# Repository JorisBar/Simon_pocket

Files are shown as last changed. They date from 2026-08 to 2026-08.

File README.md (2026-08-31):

# Simon_pocket – A pocket version of the classic Simon says game

<p align="center">
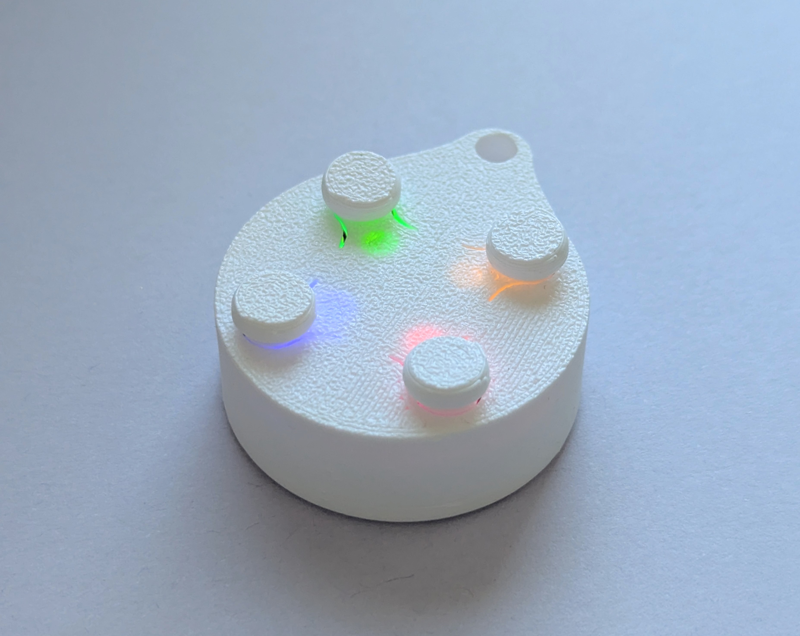
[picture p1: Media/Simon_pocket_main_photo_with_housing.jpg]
Main photo with housing
  
</p>

**Simon_pocket is a pocket sized memory training game. Players have to repeat a button sequence that gets longer each round. This project includes a custom PCB, bare metal programming for an STM32 MCU and a 3D printed housing.**

---

## Gameplay

Gameplay Diagram

---

## Hardware Architecture

Hardware Diagram

---

## Component Selection and Design Considerations

- **Microcontroller:** The STM32F030C6T6 was chosen for being inexpensive (0.5€ @ 30+ Qty) and having good documentation and support.
- **Battery:** The CR2032 was selected because of the 3V nominal voltage, compact size and availability.
- **Sound system:** Buzzers/speakers had to be omitted due to the high internal resistance of the battery.
- **Power on:** Due to space constraints, a dedicated power button was not possible. Instead, every button is configured to wake up the MCU from STOP mode.
- **Standby current:** To decrease standby current to ~6uA:
  - A low leakage current PMOS was selected.
  - No LDOs or switching regulators were used.
  - The MCU operates mostly in STOP power saving mode.

---

## PCB Design & Layout Details
<p align="center">
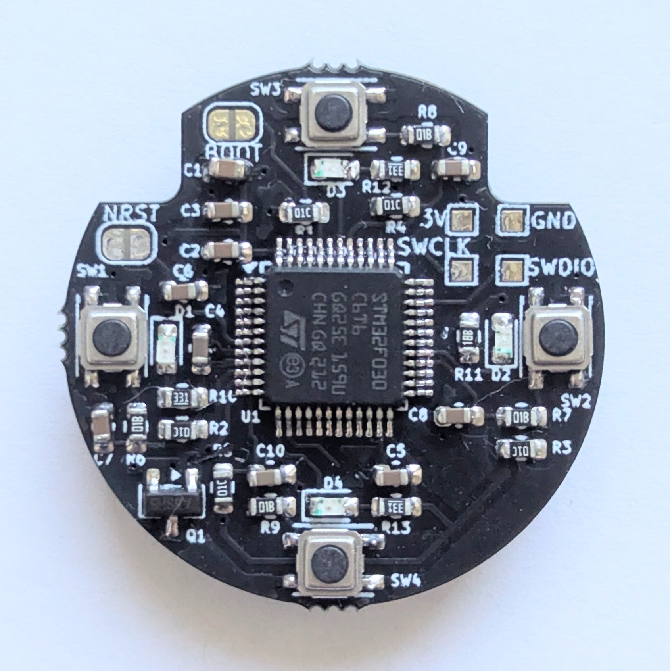
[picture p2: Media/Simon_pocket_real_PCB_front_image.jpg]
PCB top layer
  
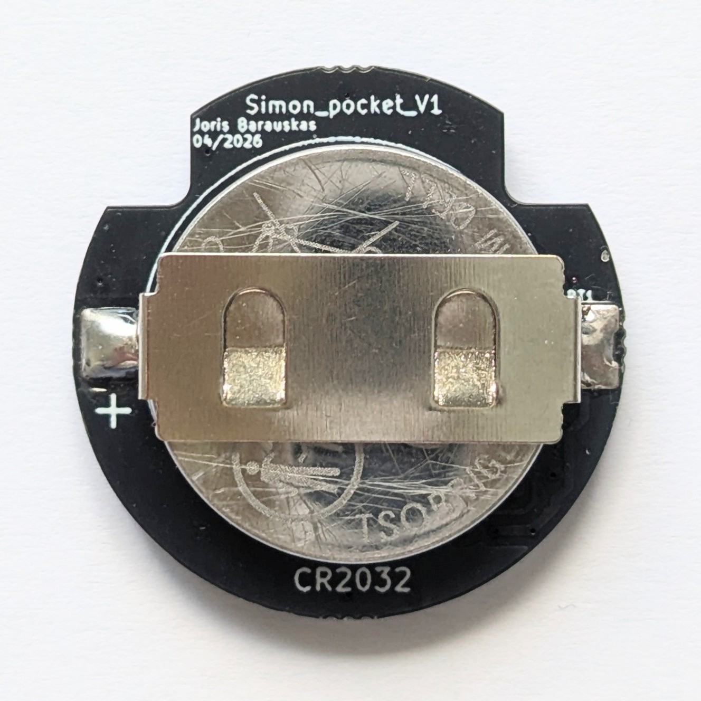
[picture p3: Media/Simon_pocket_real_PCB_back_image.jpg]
PCB bottom layer
  
</p>
<p align="center">
  PCB top layer
  PCB bottom layer
</p>

PCB Schematic
### Layer Stackup (2-Layer)
1. **Top (Signal / Power):** MCU, LED and button traces. Power distribution.
2. **Bottom (Ground / Power):** Negative battery contact and ground plane. Power distribution.

### PCB panel
A PCB panel was designed to decrease the cost of each PCB.
<p align="center">
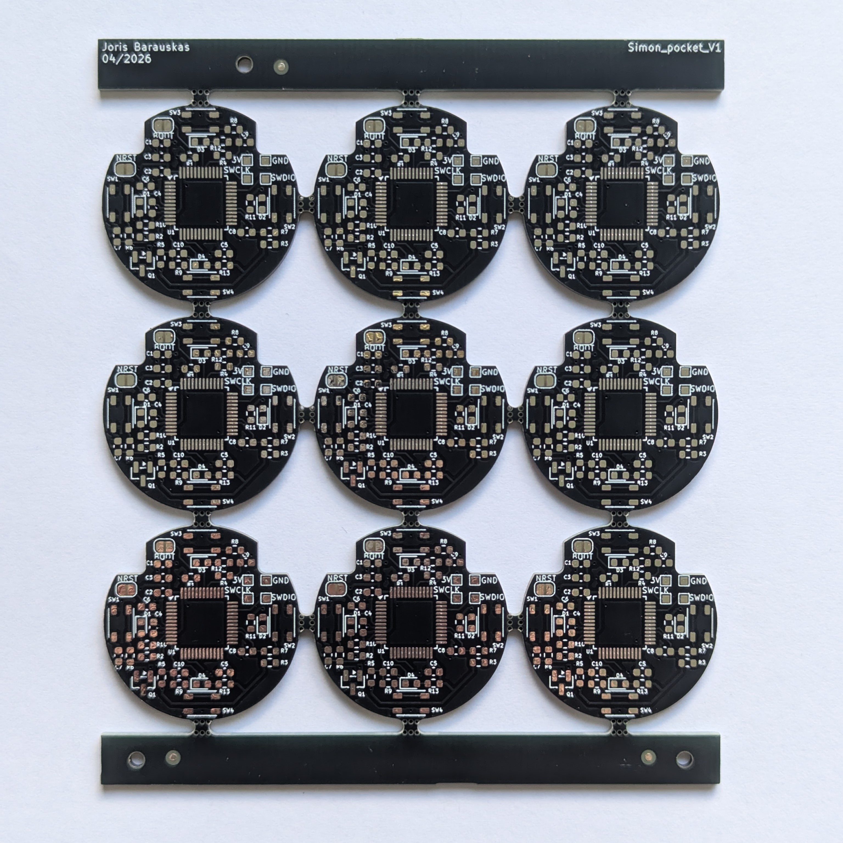
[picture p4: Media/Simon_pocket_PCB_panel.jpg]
PCB panel
  
</p>

---

## Programming
The code was written in bare metal CMSIS C using the STM32CubeIDE. To upload the code an ST-LINK V2 has to be connected to the programming contacts on the PCB.

### Code structure
Event-driven low power code structure

### State machine transitions
State machine transitions

---
## 3D modeling and printing
The housing was modeled using Autodesk Fusion. It was printed using a Bambu Lab A1 mini 3D printer.

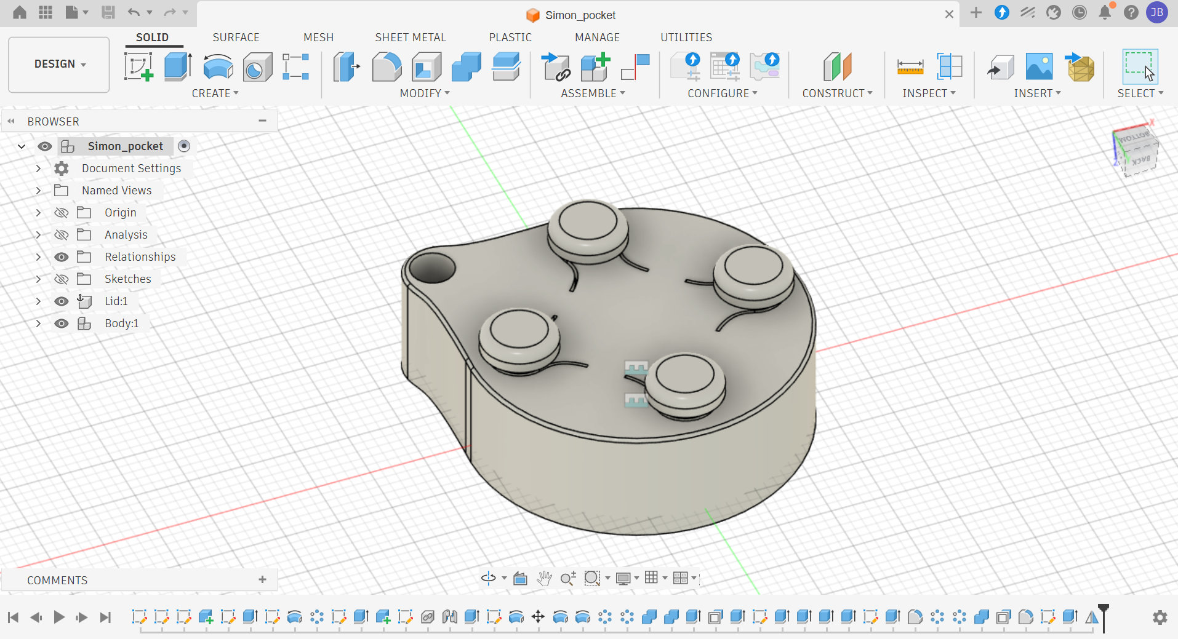
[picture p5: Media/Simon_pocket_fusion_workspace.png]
Fusion Workspace

---

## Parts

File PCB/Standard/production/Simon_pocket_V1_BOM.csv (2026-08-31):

Reference | Qty | Value | Footprint | LCSC PN
BT1 | 1 | CR2032 | My library:CR2032 slim holder | C2902340
C1 | 1 | 10u | Capacitor_SMD:C_0603_1608Metric | C6119842
C2,C3,C4,C5,C6,C7,C8,C9,C10 | 9 | 100n | Capacitor_SMD:C_0603_1608Metric | C6119867
D1 | 1 | RED | LED_SMD:LED_0603_1608Metric | C965799
D2 | 1 | GREEN | LED_SMD:LED_0603_1608Metric | C51933293
D3 | 1 | BLUE | LED_SMD:LED_0603_1608Metric | C51933294
D4 | 1 | YELLOW | LED_SMD:LED_0603_1608Metric | C51933295
Q1 | 1 | DMG2305UX-7-MS PMOS | Package_TO_SOT_SMD:SOT-23 | C7379997
R1,R2,R3,R4,R5 | 5 | 10k | Resistor_SMD:R_0603_1608Metric | C49652949
R6,R7,R8,R9 | 4 | 1k | Resistor_SMD:R_0603_1608Metric | C2907002
R10,R12,R13 | 3 | 330 | Resistor_SMD:R_0603_1608Metric | C49653542
R11 | 1 | 1.5k | Resistor_SMD:R_0603_1608Metric | C2930050
SW1,SW2,SW3,SW4 | 4 | SW_Push | My library:SW_Push mini square HansElectricity C22375378 | C22375378
U1 | 1 | STM32F030C6Tx | Package_QFP:LQFP-48_7x7mm_P0.5mm | C106925

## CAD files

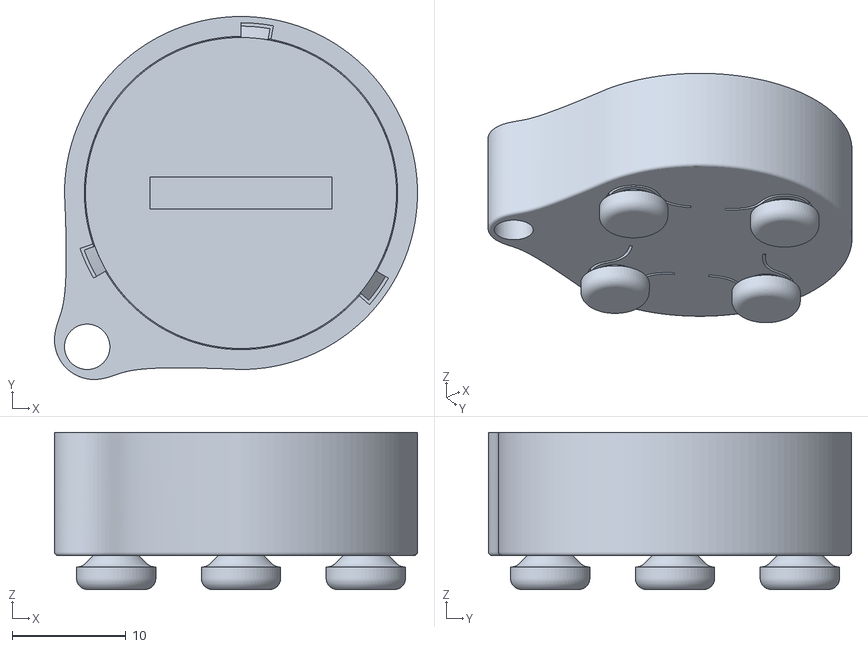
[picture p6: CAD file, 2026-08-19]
3D model/main_body_and_buttons_and_lid_V9.stl
32.0 x 32.0 x 13.8

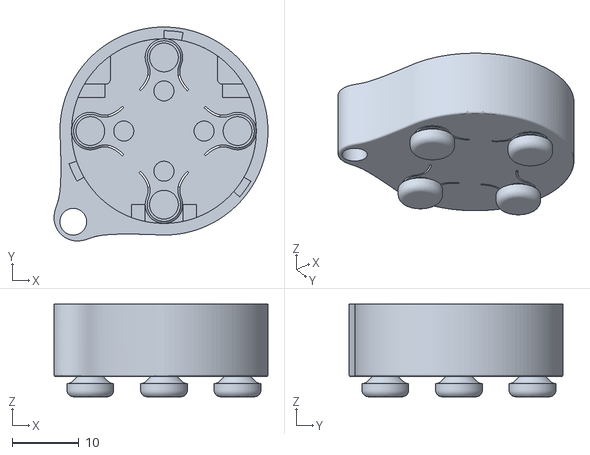
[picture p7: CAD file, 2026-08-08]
3D model/main_body_and_buttons_V8.stl
32.0 x 32.0 x 13.8

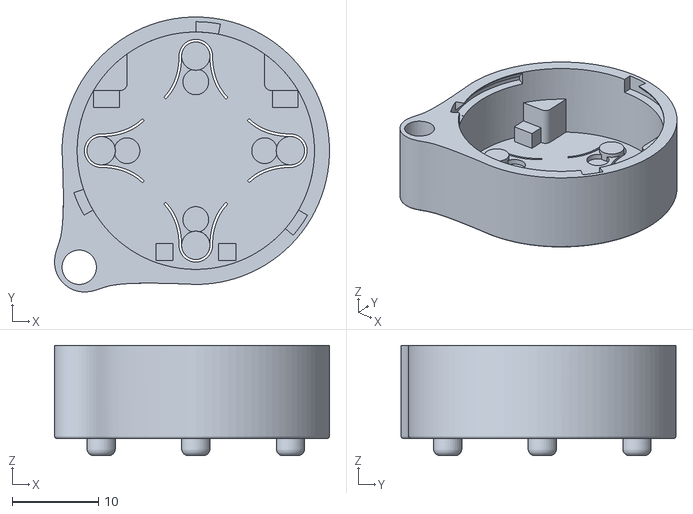
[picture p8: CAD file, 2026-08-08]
3D model/main_body_V4.stl
32.0 x 32.0 x 12.8

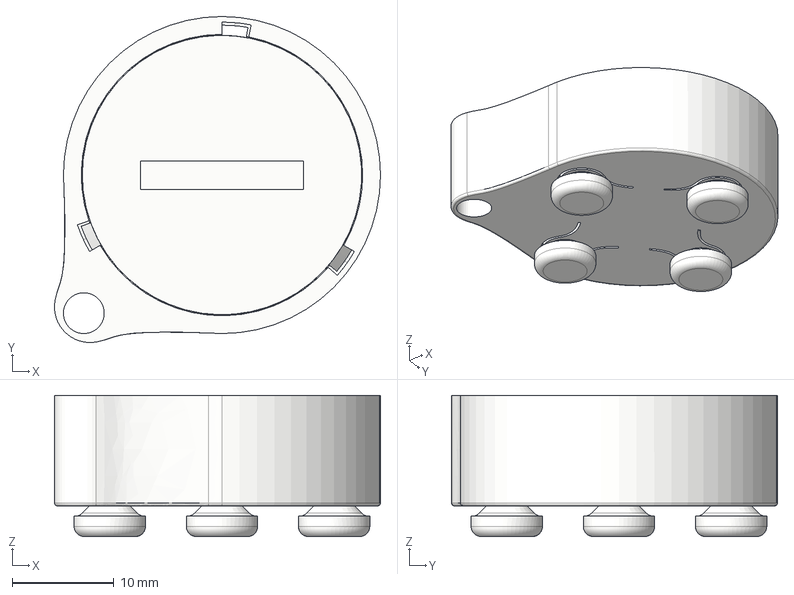
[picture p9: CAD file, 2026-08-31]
3D model/Simon_pocket_V9.step
32.0 x 32.0 x 13.8 mm

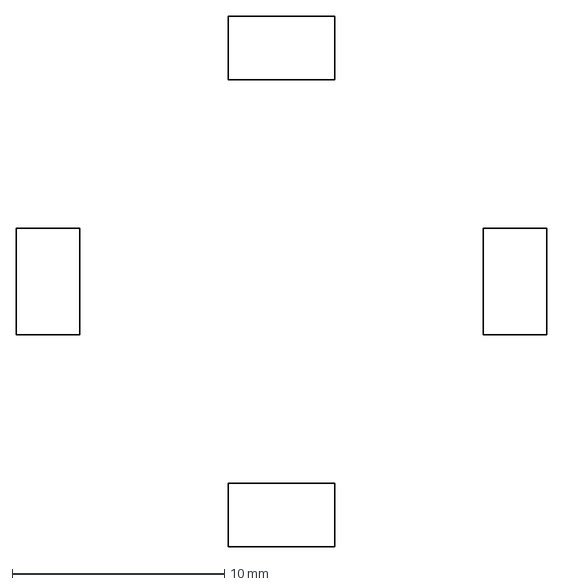
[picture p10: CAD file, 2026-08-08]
PCB/Standard/Simon says PCB buttons.dxf
25.0 x 25.0 mm

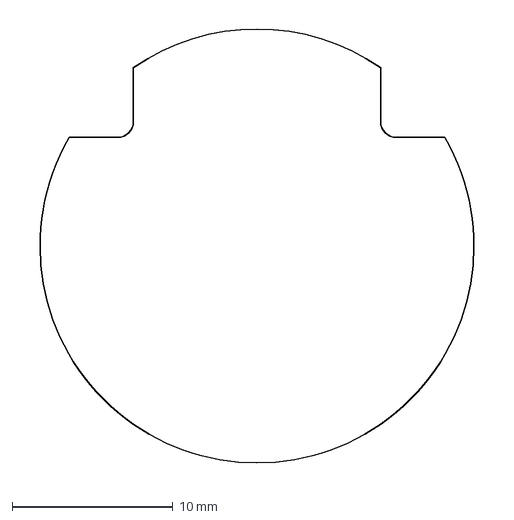
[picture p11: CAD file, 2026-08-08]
PCB/Standard/Simon says PCB.dxf
29.9 x 28.9 mm

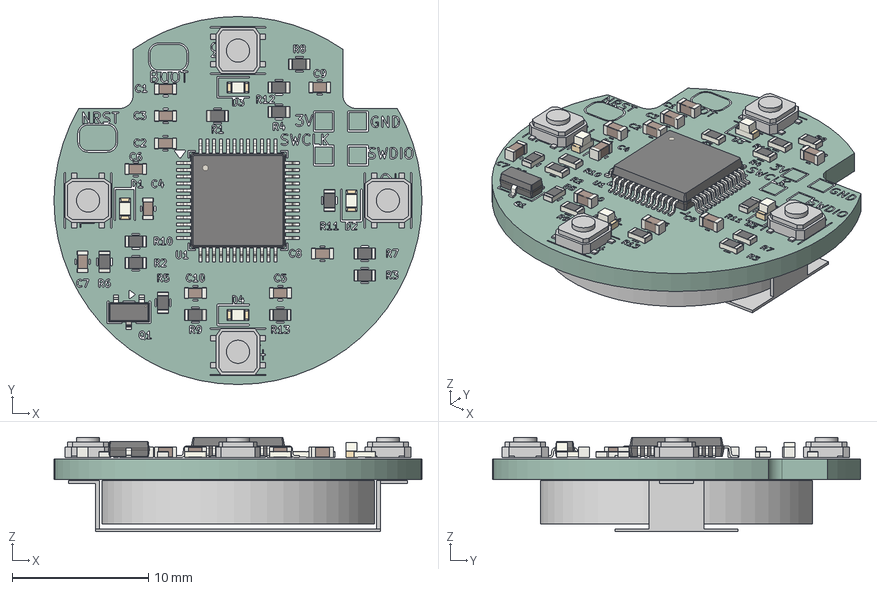
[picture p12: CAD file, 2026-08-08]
3D model/Simon_says.step
27.0 x 27.0 x 6.93 mm
KICAD small push button HansElectricity C22375378 x 4
LED_0603_1608Metric x 4
C_0603_1608Metric x 10
R_0603_1608Metric x 13
SOT-23
LQFP-48_7x7mm_P0.5mm
KICAD slim CR2032 holder
Simon_says_silkscreen x 2
Simon_says_PCB

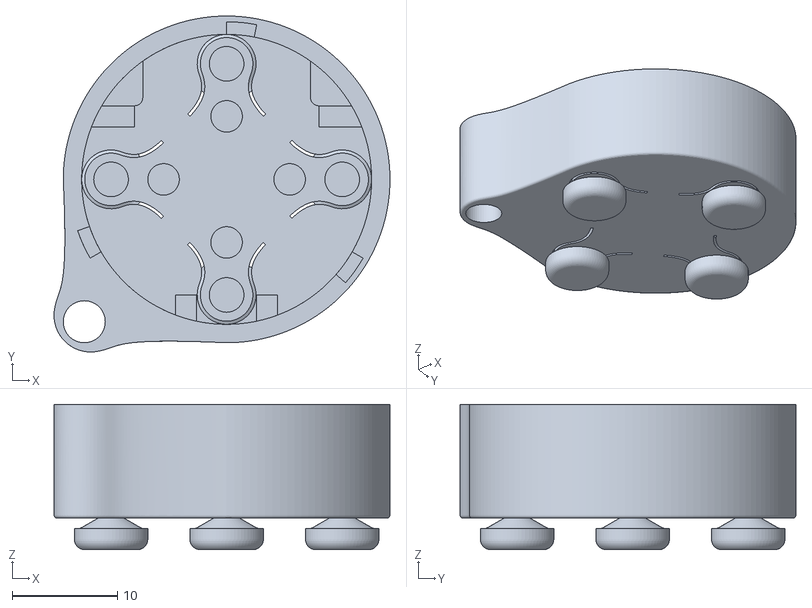
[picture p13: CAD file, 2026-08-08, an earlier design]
3D model/main_body_and_buttons_V7.stl
32.0 x 32.0 x 13.8

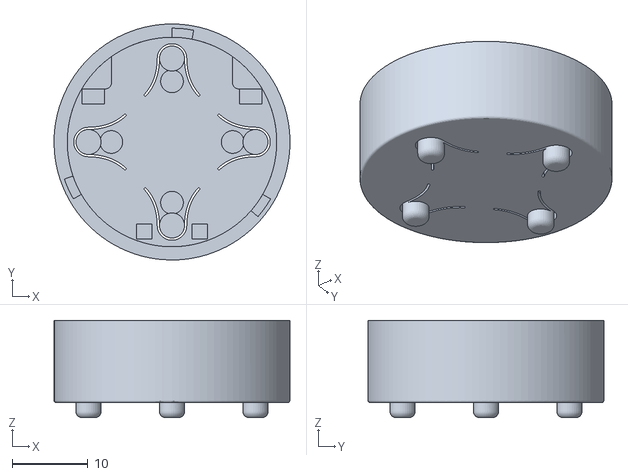
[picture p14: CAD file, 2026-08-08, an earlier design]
3D model/main_body_V3.stl
31.1 x 31.1 x 12.8

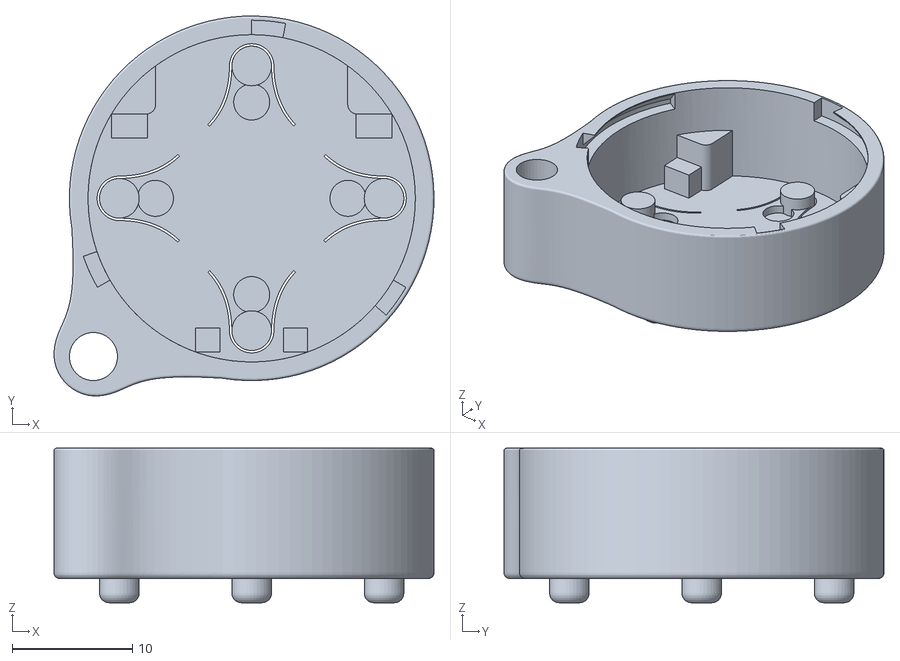
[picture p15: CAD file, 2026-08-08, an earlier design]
3D model/main_body_V1.stl
31.6 x 31.6 x 12.8

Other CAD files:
3D model/main_body_and_buttons_V5.stl
3D model/main_body_V2.stl
3D model/main_body_and_buttons_V6.stl
3D model/old_versions/Simon_pocket_V5.stl
3D model/old_versions/Simon_pocket_V2.stl
3D model/Simon_pocket_V9.f3z
3D model/old_versions/Simon_pocket_V6.stl

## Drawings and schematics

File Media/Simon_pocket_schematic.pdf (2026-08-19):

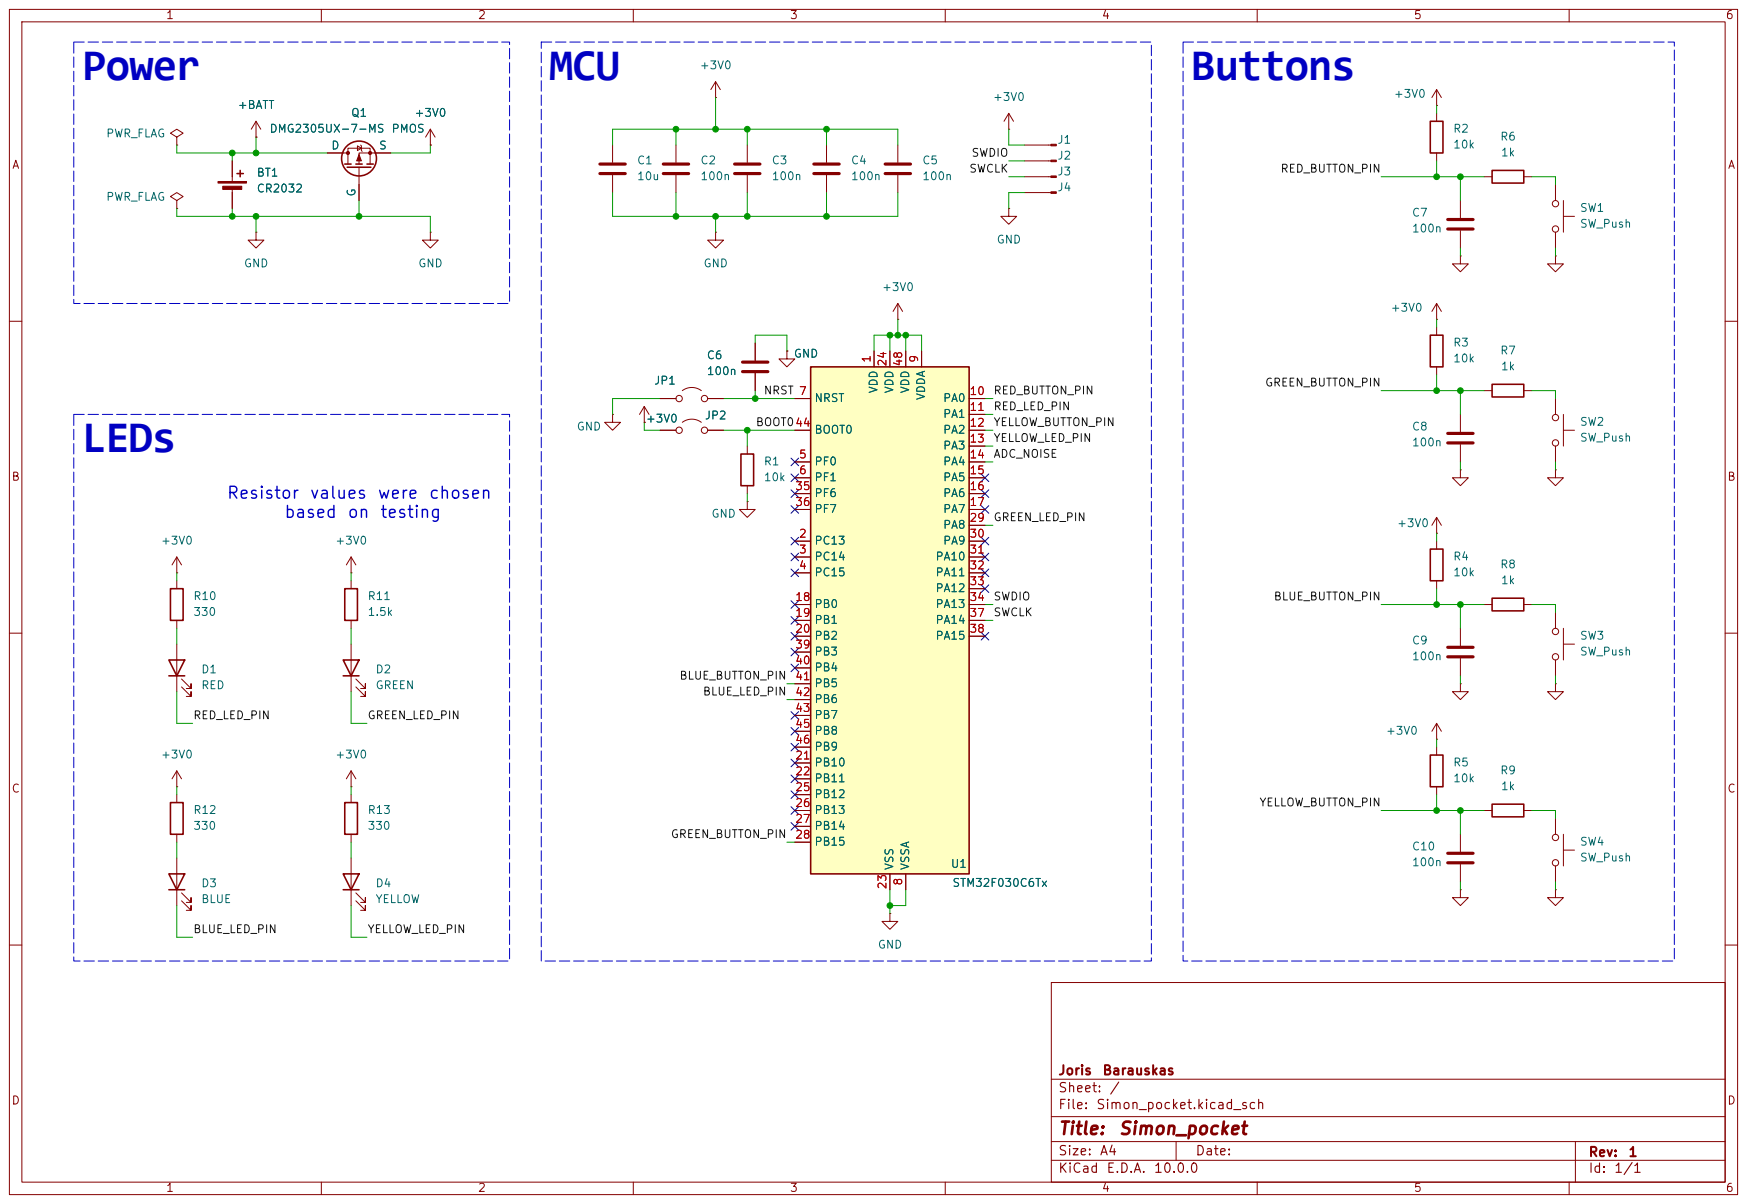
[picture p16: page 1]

1 PC13 2 PC14 3 PC15 4 PF0 5 PF1 6 NRST 7 VSSA 8 VDDA 9 PA0 10 PA1 11 PA2 12 PA3 13 PA4 14 PA5 15 PA6 16 PA7 17 PB0 18 PB1 19 PB2 20 PB10 21 PB11 22 VSS 23 VDD 24 PB12 25 PB13 26 PB14 27 PB15 28 PA8 29 PA9 30 PA10 31 PA11 32 PA12 33 PA13 34 PF6 35 PF7 36 PA14 37 PA15 38 PB3 39 PB4 40 PB5 41 PB6 42 PB7 43 BOOT0 44 PB8 45 PB9 46 VDD 48C6

1 PC13 2 PC14 3 PC15 4 PF0 5 PF1 6 NRST 7 VSSA 8 VDDA 9 PA0 10 PA1 11 PA2 12 PA3 13 PA4 14 PA5 15 PA6 16 PA7 17 PB0 18 PB1 19 PB2 20 PB10 21 PB11 22 VSS 23 VDD 24 PB12 25 PB13 26 PB14 27 PB15 28 PA8 29 PA9 30 PA10 31 PA11 32 PA12 33 PA13 34 PF6 35 PF7 36 PA14 37 PA15 38 PB3 39 PB4 40 PB5 41 PB6 42 PB7 43 BOOT0 44 PB8 45 PB9 46 VDD 48 U1
GND VDD

Resistor values were chosen

Size: A4 | Rev: 1
KiCad E.D.A. 10.0.0 | Id: 1/1

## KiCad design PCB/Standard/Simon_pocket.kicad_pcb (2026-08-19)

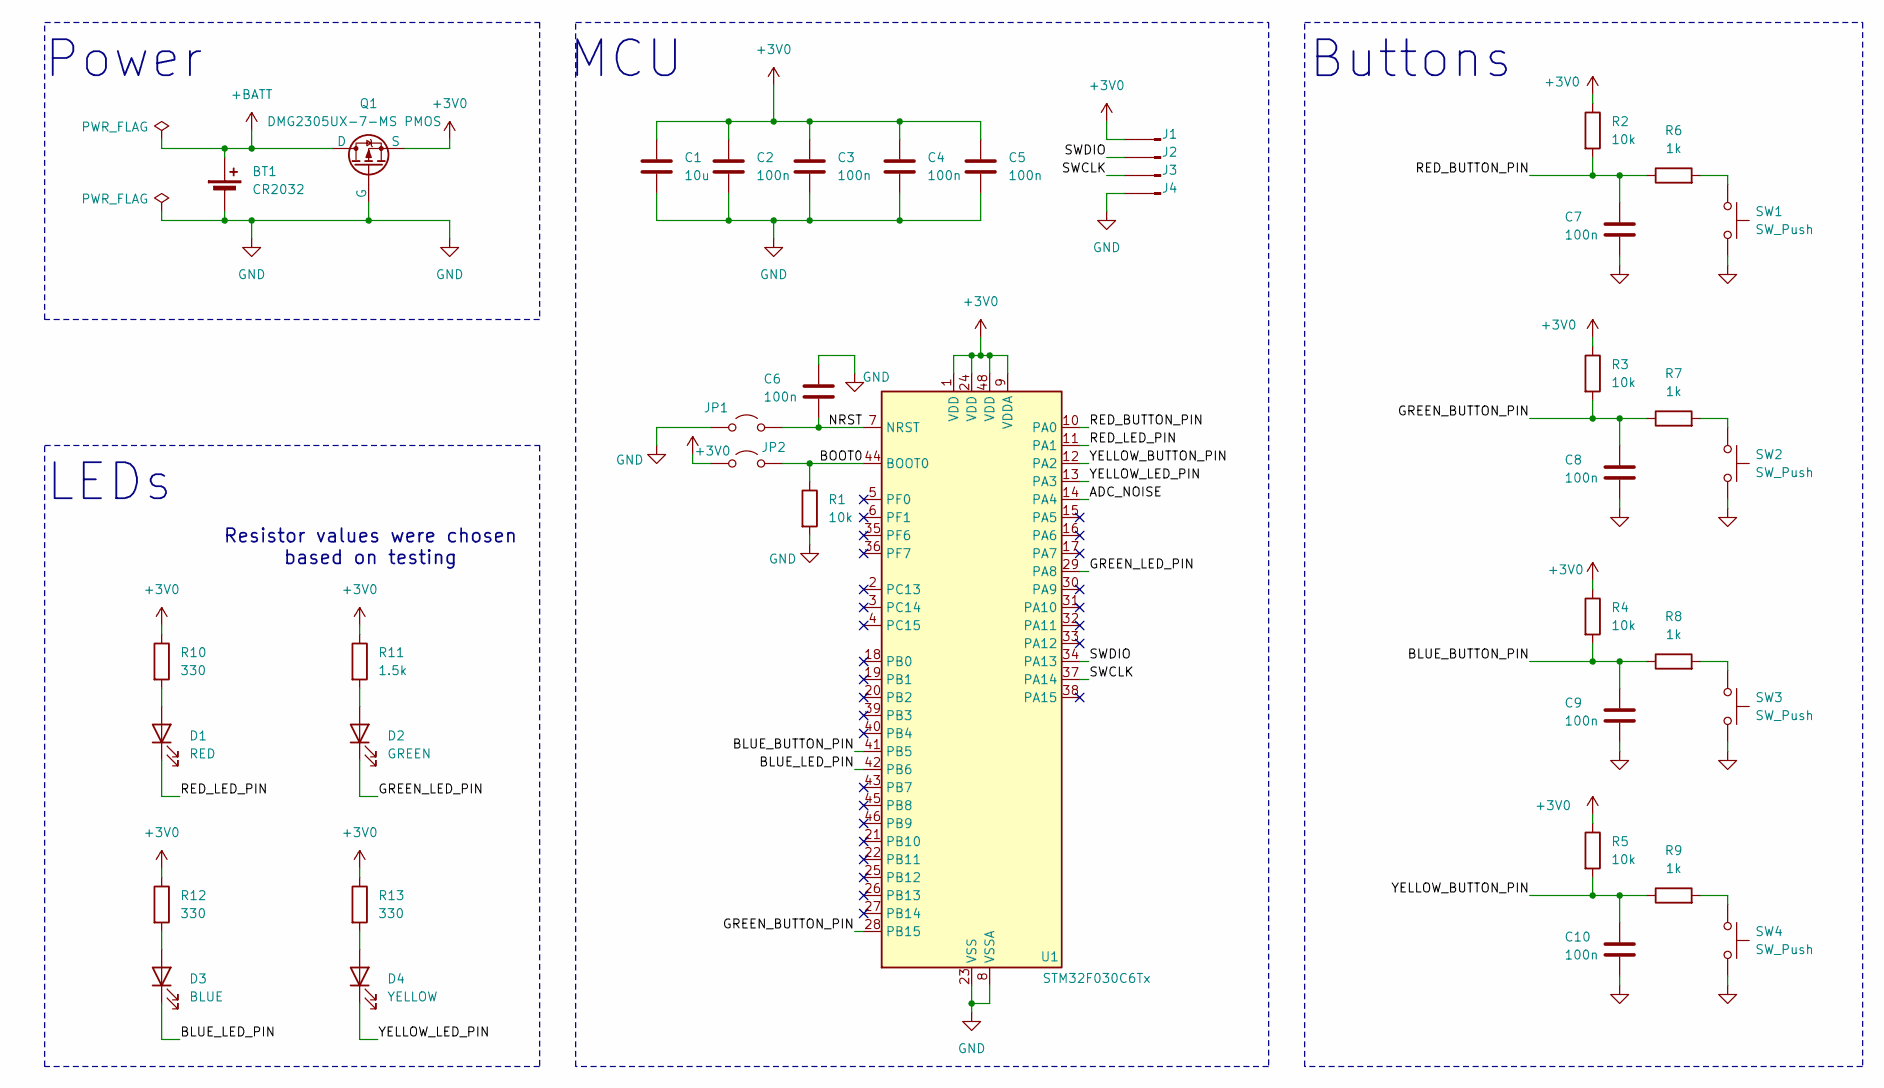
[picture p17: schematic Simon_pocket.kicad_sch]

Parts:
BT1: CR2032; CR2032 slim holder; LCSC PN C2902340
C1: 10u; C_0603_1608Metric; LCSC PN C6119842
C2, C3, C4, C5, C6, C7, C8, C9, C10: 100n; C_0603_1608Metric; LCSC PN C6119867
D1: RED; LED_0603_1608Metric; LCSC PN C965799
D2: GREEN; LED_0603_1608Metric; LCSC PN C51933293
D3: BLUE; LED_0603_1608Metric; LCSC PN C51933294
D4: YELLOW; LED_0603_1608Metric; LCSC PN C51933295
J1, J2, J3, J4: Conn_01x01_Pin; TestPoint_Pad_1.0x1.0mm
JP1, JP2: Jumper_2_Open; SolderJumper-2_P1.3mm_Open_RoundedPad1.0x1.5mm
Q1: DMG2305UX-7-MS PMOS; SOT-23; LCSC PN C7379997
R1, R2, R3, R4, R5: 10k; R_0603_1608Metric; LCSC PN C49652949
R6, R7, R8, R9: 1k; R_0603_1608Metric; LCSC PN C2907002
R10, R12, R13: 330; R_0603_1608Metric; LCSC PN C49653542
R11: 1.5k; R_0603_1608Metric; LCSC PN C2930050
SW1, SW2, SW3, SW4: SW_Push; SW_Push mini square HansElectricity C22375378; LCSC PN C22375378
U1: STM32F030C6Tx; LQFP-48_7x7mm_P0.5mm; LCSC PN C106925

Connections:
+3V0: C1.1, C2.1, C3.1, C4.1, C5.1, J1.1 (Pin_1_1), JP2.1 (A), Q1.2 (S), R2.1, R3.1, R4.1, R5.1, R10.1, R11.1, R12.1, R13.1, U1.1 (VDD), U1.9 (VDDA), U1.24 (VDD), U1.48 (VDD)
+BATT: BT1.1 (+), Q1.3 (D)
/ADC_NOISE: U1.14 (PA4)
/BLUE_BUTTON_PIN: C9.1, R4.2, R8.1, U1.41 (PB5)
/BLUE_LED_PIN: D3.1 (K), U1.42 (PB6)
/BOOT0: JP2.2 (B), R1.1, U1.44 (BOOT0)
/GREEN_BUTTON_PIN: C8.1, R3.2, R7.1, U1.28 (PB15)
/GREEN_LED_PIN: D2.1 (K), U1.29 (PA8)
/NRST: C6.2, JP1.2 (B), U1.7 (NRST)
/RED_BUTTON_PIN: C7.1, R2.2, R6.1, U1.10 (PA0)
/RED_LED_PIN: D1.1 (K), U1.11 (PA1)
/SWCLK: J3.1 (Pin_1_1), U1.37 (PA14)
/SWDIO: J2.1 (Pin_1_1), U1.34 (PA13)
/YELLOW_BUTTON_PIN: C10.1, R5.2, R9.1, U1.12 (PA2)
/YELLOW_LED_PIN: D4.1 (K), U1.13 (PA3)
GND: BT1.2 (-), C1.2, C2.2, C3.2, C4.2, C5.2, C6.1, C7.2, C8.2, C9.2, C10.2, J4.1 (Pin_1_1), JP1.1 (A), Q1.1 (G), R1.2, SW1.2, SW2.2, SW3.2, SW4.2, U1.8 (VSSA), U1.23 (VSS), U1.47 (VSS)
unnamed: D1.2 (A), R10.2
unnamed: D2.2 (A), R11.2
unnamed: D3.2 (A), R12.2
unnamed: D4.2 (A), R13.2
unnamed: R6.2, SW1.1
unnamed: R7.2, SW2.1
unnamed: R8.2, SW3.1
unnamed: R9.2, SW4.1

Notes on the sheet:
LEDs
Resistor values were chosen based on testing
Buttons
MCU
Power

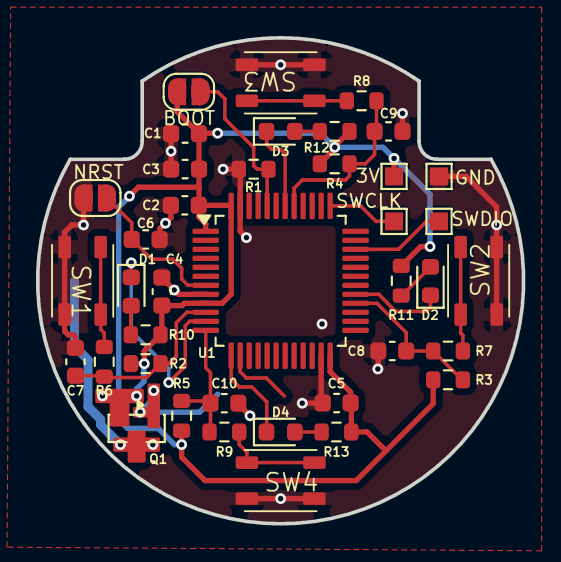
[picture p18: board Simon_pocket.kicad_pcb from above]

Board: 2 copper layers, 27.0 x 27.0 mm, 40 parts (1 on the bottom side), 23 nets.

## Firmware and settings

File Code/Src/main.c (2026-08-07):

#include "hardware.h"
#include "stm32f030x6.h"
#include "game.h"

int main(void)
{
    system_clock_config();
    gpio_init();
    adc_init();
    rtc_init();
    exti_init();

    while (1)
    {
        SCB->SCR |= SCB_SCR_SLEEPDEEP_Msk;
        PWR->CR &= ~PWR_CR_PDDS;
        PWR->CR |= PWR_CR_LPDS;

        __WFI();
    }
}

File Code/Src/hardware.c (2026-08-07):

#include "hardware.h"
#include "game.h"

typedef struct {
    GPIO_TypeDef *btn_port;
    uint8_t       btn_pin;
    GPIO_TypeDef *led_port;
    uint8_t       led_pin;
} simon_color_config_t;

static const simon_color_config_t SIMON_COLORS[COLOR_COUNT] = {
    [COLOR_RED]    = { GPIOA,  0,  GPIOA,  1 },
    [COLOR_GREEN]  = { GPIOB, 15,  GPIOA,  8 },
    [COLOR_BLUE]   = { GPIOB,  5,  GPIOB,  6 },
    [COLOR_YELLOW] = { GPIOA,  2,  GPIOA,  3 },
};


static uint8_t rtc_calculate_bcd_time(uint8_t delay_sec)
{
    uint8_t bcd = RTC->TR & (RTC_TR_ST_Msk | RTC_TR_SU_Msk);
    (void)RTC->DR;

    uint8_t seconds = (bcd >> 4) * 10 + (bcd & 0xF);
    seconds += delay_sec;

    if (seconds >= 60) {
        seconds -= 60;
    }
    return ((seconds / 10) << 4) | (seconds % 10);
}


// HARDWARE CONFIGURATION
void system_clock_config(void)
{
    RCC->CR |= RCC_CR_HSION;
    while (!(RCC->CR & RCC_CR_HSIRDY));
    RCC->CSR |= RCC_CSR_LSION;
    while (!(RCC->CSR & RCC_CSR_LSIRDY));

    RCC->CFGR |= RCC_CFGR_HPRE_DIV128;

    RCC->AHBENR |= RCC_AHBENR_GPIOAEN;
    RCC->AHBENR |= RCC_AHBENR_GPIOBEN;

    RCC->APB1ENR |= RCC_APB1ENR_PWREN;
    RCC->APB2ENR |= RCC_APB2ENR_SYSCFGEN;

    PWR->CR |= PWR_CR_DBP;
    RCC->BDCR |= RCC_BDCR_RTCEN;
    RCC->BDCR |= RCC_BDCR_RTCSEL_LSI;
}

void gpio_init(void)
{
    RCC->AHBENR |= RCC_AHBENR_GPIOAEN | RCC_AHBENR_GPIOBEN |
                   RCC_AHBENR_GPIOCEN | RCC_AHBENR_GPIOFEN;

    GPIOA->MODER = 0xEBFFFFFF; // Debugger alternate function
    GPIOB->MODER = 0xFFFFFFFF;
    GPIOC->MODER = 0xFFFFFFFF;
    GPIOF->MODER = 0xFFFFFFFF;

    // LED pins
    GPIOA->MODER &= ~(GPIO_MODER_MODER0 | GPIO_MODER_MODER2);
    GPIOB->MODER &= ~(GPIO_MODER_MODER5 | GPIO_MODER_MODER15);

    // Button pins
    GPIOA->MODER &= ~(GPIO_MODER_MODER1 | GPIO_MODER_MODER3 | GPIO_MODER_MODER8);
    GPIOB->MODER &= ~(GPIO_MODER_MODER6);
    GPIOA->MODER |= (GPIO_MODER_MODER1_0 | GPIO_MODER_MODER3_0 | GPIO_MODER_MODER8_0);
    GPIOB->MODER |= (GPIO_MODER_MODER6_0);

    RCC->AHBENR &= ~(RCC_AHBENR_GPIOCEN | RCC_AHBENR_GPIOFEN);

    led_toggle_all(false);
}

void exti_init(void)
{
    SYSCFG->EXTICR[0] |= SYSCFG_EXTICR1_EXTI0_PA | SYSCFG_EXTICR1_EXTI2_PA;
    SYSCFG->EXTICR[1] |= SYSCFG_EXTICR2_EXTI5_PB;
    SYSCFG->EXTICR[3] |= SYSCFG_EXTICR4_EXTI15_PB;
    EXTI->IMR |= EXTI_IMR_MR0 | EXTI_IMR_MR2 | EXTI_IMR_MR5 | EXTI_IMR_MR15;
    EXTI->FTSR |= EXTI_FTSR_TR0 | EXTI_FTSR_TR2 | EXTI_FTSR_TR5 | EXTI_FTSR_TR15;
    EXTI->PR = EXTI_IMR_MR0_Msk | EXTI_IMR_MR2_Msk | EXTI_IMR_MR5_Msk | EXTI_IMR_MR15_Msk;
    NVIC_EnableIRQ(EXTI0_1_IRQn);
    NVIC_EnableIRQ(EXTI2_3_IRQn);
    NVIC_EnableIRQ(EXTI4_15_IRQn);
}

void rtc_init(void)
{
    RTC->WPR = 0xCA;
    RTC->WPR = 0x53;

    RTC->ISR &= ~RTC_ISR_ALRAF;
    RTC->CR &= ~RTC_CR_ALRAE;
    while (!(RTC->ISR & RTC_ISR_ALRAWF));
    RTC->ISR |= RTC_ISR_INIT;
    while (!(RTC->ISR & RTC_ISR_INITF));

    RTC->PRER = (0x7F << RTC_PRER_PREDIV_A_Pos);
    RTC->PRER |= RTC_PREDIV_SS;

    RTC->ISR &= ~RTC_ISR_INIT;
    RTC->ISR &= ~RTC_ISR_RSF;
    while (!(RTC->ISR & RTC_ISR_RSF));

    EXTI->PR = EXTI_PR_PR17;
    EXTI->IMR |= EXTI_IMR_MR17;
    EXTI->RTSR |= EXTI_RTSR_TR17;

    RTC->ALRMAR |= RTC_ALRMAR_MSK4_Msk | RTC_ALRMAR_MSK3_Msk | RTC_ALRMAR_MSK2_Msk;
    RTC->ALRMAR &= ~(RTC_ALRMAR_ST_Msk | RTC_ALRMAR_SU_Msk);
    RTC->CR |= RTC_CR_ALRAIE;
    EXTI->IMR |= EXTI_IMR_MR17_Msk;
    EXTI->RTSR |= EXTI_RTSR_TR17_Msk;
    NVIC_EnableIRQ(RTC_IRQn);
}

void adc_init(void)
{
    RCC->CR2 |= RCC_CR2_HSI14ON;
    while ((RCC->CR2 & RCC_CR2_HSI14RDY) == 0);
    RCC->APB2ENR |= RCC_APB2ENR_ADC1EN;

    if ((ADC1->CR & ADC_CR_ADEN) != 0) {
        ADC1->CR |= ADC_CR_ADDIS;
        while ((ADC1->CR & ADC_CR_ADEN) != 0);
    }
    ADC1->CR |= ADC_CR_ADCAL;
    while ((ADC1->CR & ADC_CR_ADCAL) != 0);

    RCC->CR2 &= ~RCC_CR2_HSI14ON;
}


// --- HARDWARE ACTIONS ---
void adc_enable(void)
{
    RCC->CR2 |= RCC_CR2_HSI14ON;
    while ((RCC->CR2 & RCC_CR2_HSI14RDY) == 0);

    ADC1->ISR |= ADC_ISR_ADRDY;
    ADC1->CR |= ADC_CR_ADEN;
    while ((ADC1->ISR & ADC_ISR_ADRDY) == 0);

    ADC1->CHSELR = ADC_CHSELR_CHSEL4;
}

void adc_disable(void)
{
    if (ADC1->CR & ADC_CR_ADSTART) {
        ADC1->CR |= ADC_CR_ADSTP;
        while (ADC1->CR & ADC_CR_ADSTP);
    }
    if (ADC1->CR & ADC_CR_ADEN) {
        ADC1->CR |= ADC_CR_ADDIS;
        while ((ADC1->CR & ADC_CR_ADEN) != 0);
    }
    RCC->CR2 &= ~RCC_CR2_HSI14ON;
}

uint8_t adc_generate_random_2bit(void)
{
    ADC1->CR |= ADC_CR_ADSTART;
    while ((ADC1->ISR & ADC_ISR_EOC) == 0);
    uint16_t raw_adc = ADC1->DR;
    raw_adc ^= raw_adc << 13;
    raw_adc ^= raw_adc >> 17;
    raw_adc ^= raw_adc << 5;
    return (raw_adc & 0x03);
}
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

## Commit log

2026-08-08 Added KiCAD files
    [Lid twisting test.stl, Main body printing test beta.3mf, Main body twisting test.stl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]
2026-08-12 Create README.md with project overview and details
    Added detailed project documentation including design considerations, component selection, system architecture, PCB design, validation results, and tools used.
2026-08-19 Add design considerations to README
    Added design considerations section to README with details on size and standby current.
2026-08-19 adjusted PCB files
    [Simon says PCB buttons.dxf, Simon says PCB.dxf, Simon_pocket.kicad_pcb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]
2026-08-19 Added KiCAD screenshots
2026-08-19 Fixed PCB screenshot file formats
    [Simon_pocket.kicad_pcb]
2026-08-19 Revise PCB design details in README
    Updated PCB design section with images and removed old screenshot.
2026-08-19 Fixed README image file formats
    [Simon_pocket.kicad_pcb]
2026-08-19 Change image formats from SVG to PNG in README
    Updated image formats in README for hardware diagrams and PCB layout.
2026-08-19 Fix image references in README.md
    Updated images in the README for hardware block diagram and PCB design.
2026-08-20 fixed PCB image bacground size
2026-08-20 Remove top layer image from PCB design details
    Removed the top layer image from the PCB design section.
2026-08-20 Add top layer PCB image to README
    Updated the README to include the top layer PCB image.
2026-08-20 Remove cost details for STM32F030C6T6
    Removed mention of microcontroller cost and documentation.
2026-08-21 Added Fusion and real PCB images
2026-08-28 Added main photo with housing
2026-08-28 Replace PCB images with new photos
    Updated images in the README to reflect the latest design.
2026-08-28 Changed PCB front image
2026-08-31 Finished KiCAD files
    [Lid twisting test.stl, Main body printing test beta.3mf, Main body twisting test.stl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]
2026-08-31 Revise README for clarity and add PCB panel section
    Updated project description for clarity and added a section about the PCB panel.
